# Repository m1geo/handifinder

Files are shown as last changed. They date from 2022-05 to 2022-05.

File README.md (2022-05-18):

# Handi-Finder
This repository is a KiCad 5.1 design of the published Handi-Finder DF project. 

The Handi-Finder Project is a radio direction finder, which connectso to an existing radio receiver such as a hand-held radio, and adds some direction finding capabiltiy to it.

The device works by switching between the two wire antennas mounted on H1 and H2 on the PCB. When the two antennas are directly lined towards the source of transmission, the arriving signal is in phase between both antennas. When the Handi-Finder is held non-squarely toward the signal source, the phase difference between the two wire antennas causes the switching frequency (here, approximately 1 kHz) to be audiable with loudness proportional to phase difference.

There are many resources online for this project, with some links here:
- [May 1993 QST Article by Bob K8DTS](https://www.ve5nn.ca/images/FoxHunt/handi-finder.pdf)
- [The HANDI-Finder](https://www.handi-finder.com/)

The [outputs](https://github.com/m1geo/handifinder/tree/main/Outputs) folder contains the Gerber files which can be zipped up and sent for manufacture at your chosen board-house.

## 3D View

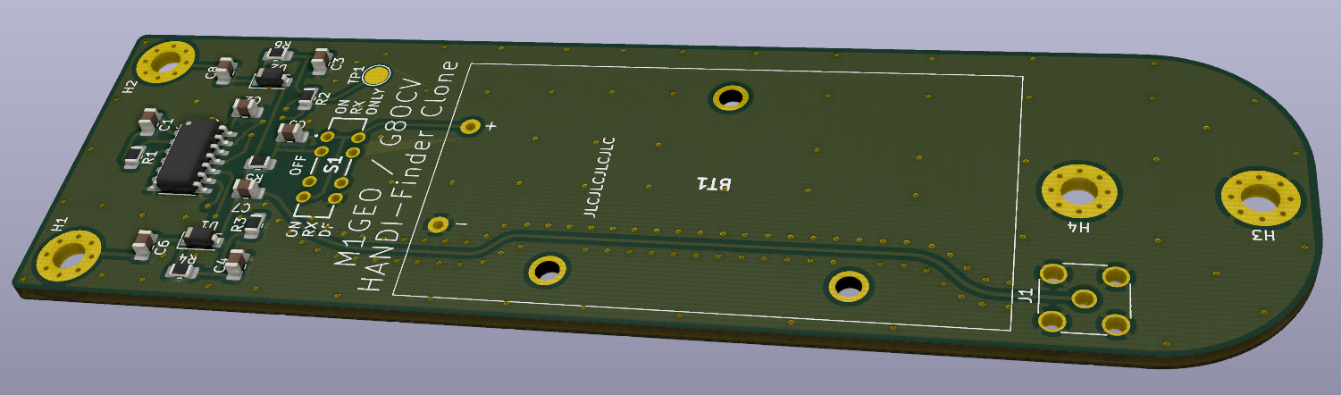
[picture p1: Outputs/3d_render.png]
3D View


## Schematic

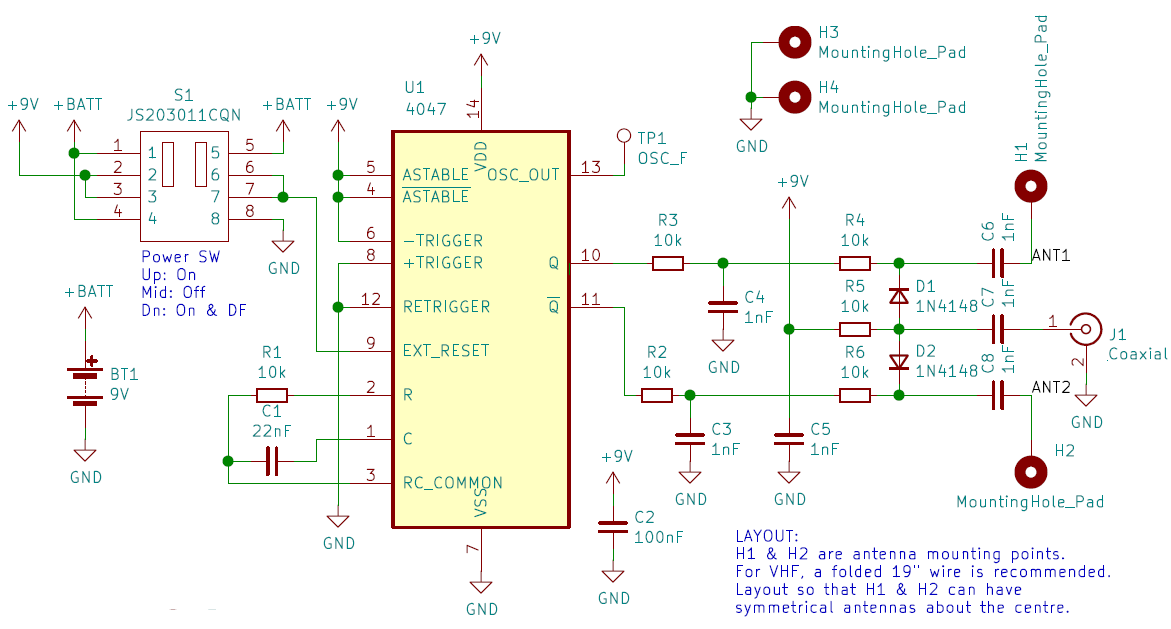
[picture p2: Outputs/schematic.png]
Schematic


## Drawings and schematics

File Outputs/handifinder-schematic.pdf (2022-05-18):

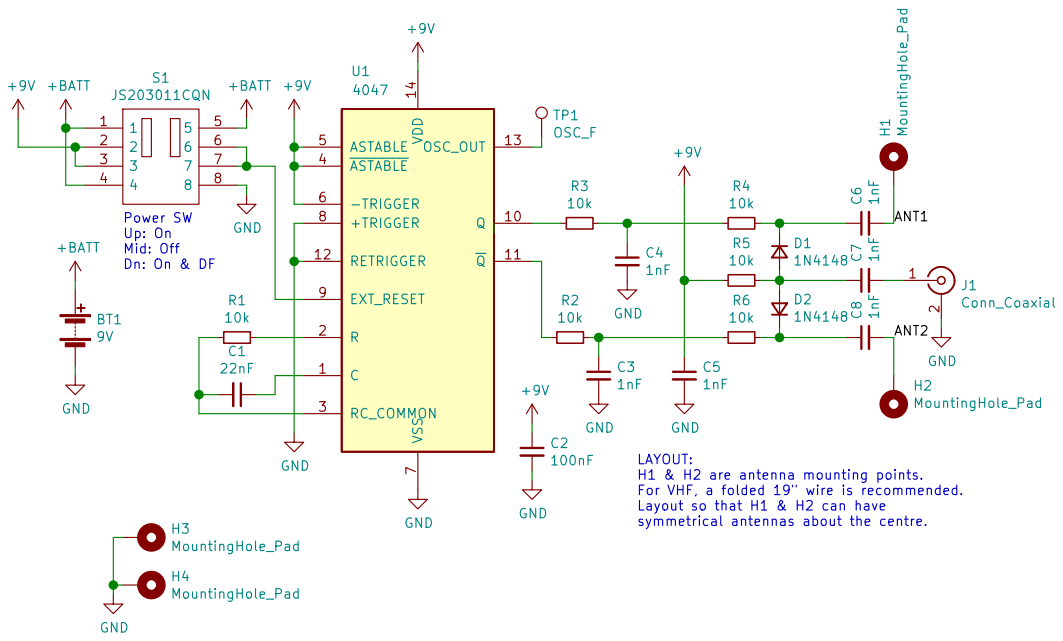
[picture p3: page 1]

ANT1 ANT2 Power SW
Up: On Mid: Off Dn: On & DF

https://github.com/m1geo/handifinder LAYOUT: H1 & H2 are antenna mounting points. For VHF, a folded 19" wire is recommended. Layout so that H1 & H2 can have

symmetrical antennas about the centre.

Id: 1/1 Title: HANDI-Finder File: handifinder.sch Sheet: / George Smart M1GEO

https://www.george-smart.co.uk/

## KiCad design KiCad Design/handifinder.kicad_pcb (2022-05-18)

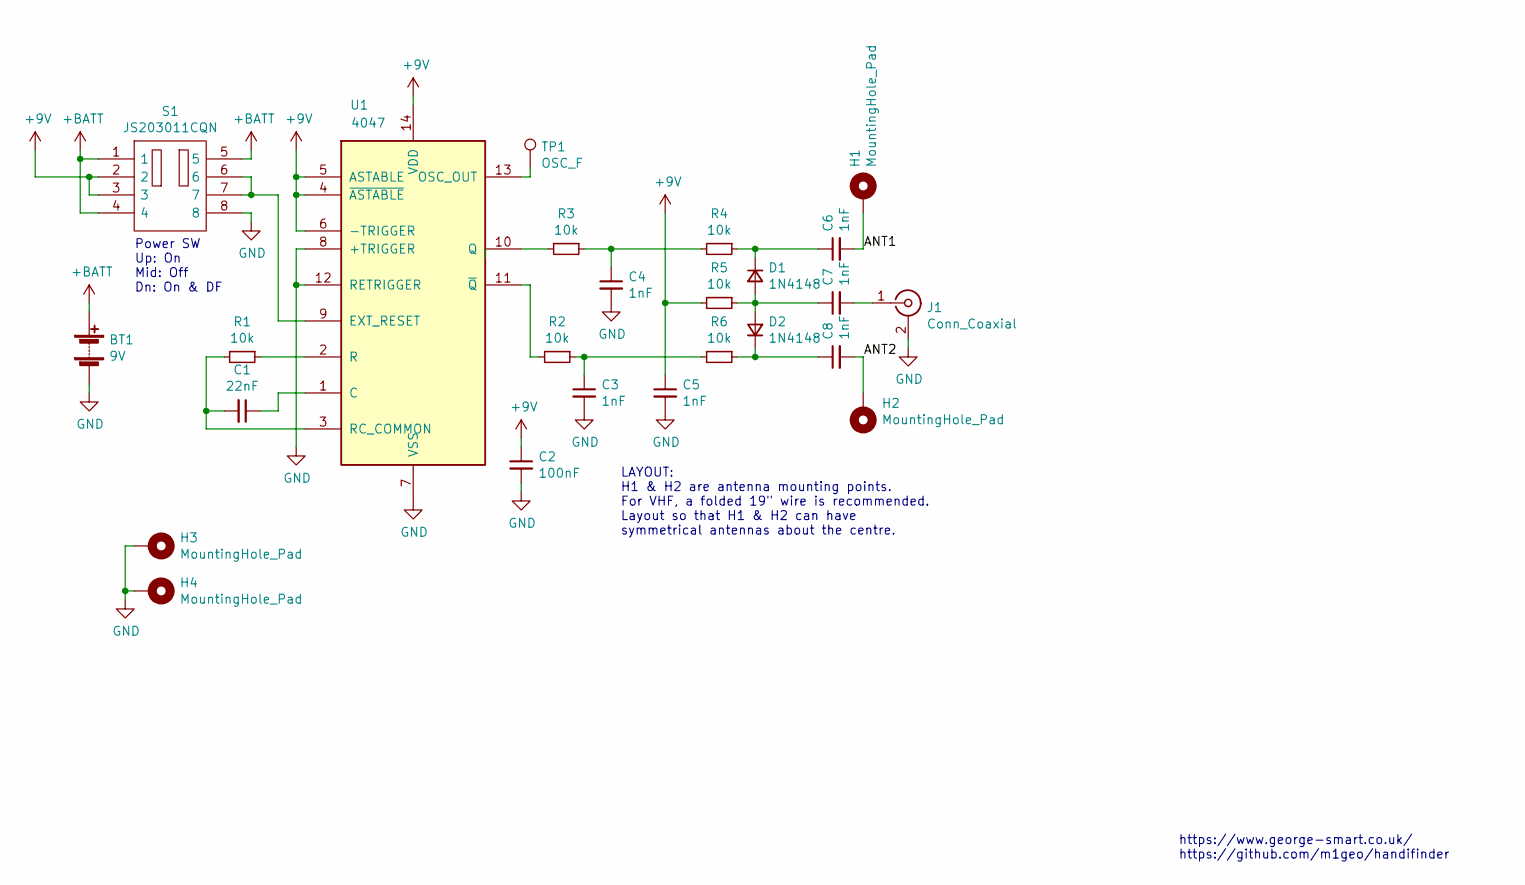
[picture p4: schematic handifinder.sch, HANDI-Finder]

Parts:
BT1: 9V; BH9VPC
C1: 22nF; C_0805_2012Metric_Pad1.18x1.45mm_HandSolder
C2: 100nF; C_0805_2012Metric_Pad1.18x1.45mm_HandSolder
C3, C4, C5, C6, C7, C8: 1nF; C_0805_2012Metric_Pad1.18x1.45mm_HandSolder
D1, D2: 1N4148; D_SOD-123
H1, H2, H3, H4: MountingHole_Pad; MountingHole_3.2mm_M3_Pad_Via
J1: Conn_Coaxial; SMA_Amphenol_132134_Vertical
R1, R2, R3, R4, R5, R6: 10k; R_0805_2012Metric_Pad1.20x1.40mm_HandSolder
S1: JS203011CQN; JS-DP3T; Manufacturer_Part_Number JS203011CQN; Mouser Part Number 611-JS203011CQN
TP1: OSC_F; TestPoint_Pad_D2.5mm
U1: 4047; SOIC-14_3.9x8.7mm_P1.27mm

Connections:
+9V: C2.1, C5.1, R5.2, S1.2, S1.3, U1.4 (~ASTABLE), U1.5 (ASTABLE), U1.6 (-TRIGGER), U1.14 (VDD)
+BATT: BT1.1 (+), S1.1, S1.4, S1.5
/ANT1: C6.2, H1.1
/ANT2: C8.2, H2.1
GND: BT1.2 (-), C2.2, C3.2, C4.2, C5.2, H3.1, H4.1, J1.2 (Ext), S1.8, U1.7 (VSS), U1.8 (+TRIGGER), U1.12 (RETRIGGER)
unnamed: C1.1, U1.1 (C)
unnamed: C1.2, R1.2, U1.3 (RC_COMMON)
unnamed: C3.1, R2.1, R6.2
unnamed: C4.1, R3.1, R4.2
unnamed: C6.1, D1.1 (K), R4.1
unnamed: C7.1, D1.2 (A), D2.2 (A), R5.1
unnamed: C7.2, J1.1 (In)
unnamed: C8.1, D2.1 (K), R6.1
unnamed: R1.1, U1.2 (R)
unnamed: R2.2, U1.11 (~Q)
unnamed: R3.2, U1.10 (Q)
unnamed: S1.6, S1.7, U1.9 (EXT_RESET)
unnamed: TP1.1, U1.13 (OSC_OUT)

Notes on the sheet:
https://www.george-smart.co.uk/ https://github.com/m1geo/handifinder
LAYOUT: H1 & H2 are antenna mounting points. For VHF, a folded 19" wire is recommended. Layout so that H1 & H2 can have symmetrical antennas about the centre.
Power SW Up: On Mid: Off Dn: On & DF

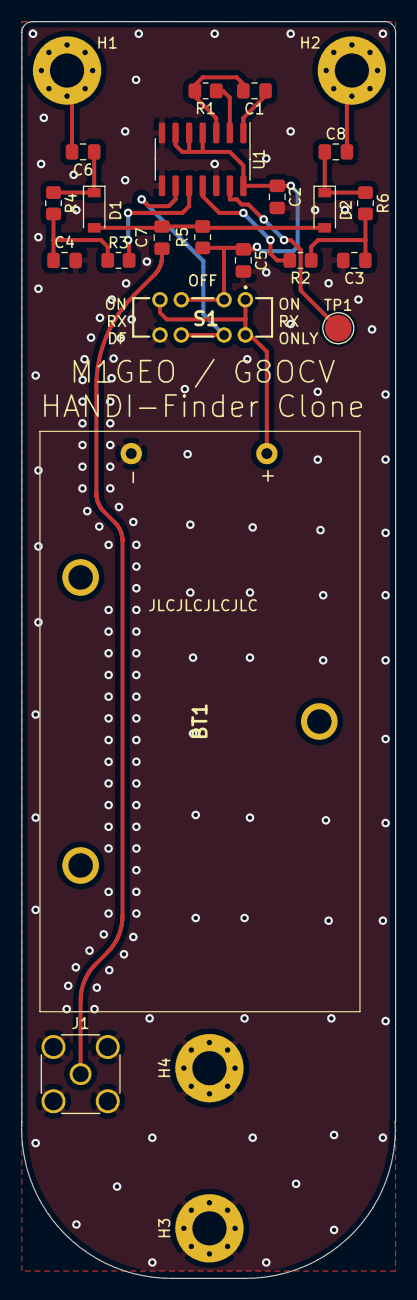
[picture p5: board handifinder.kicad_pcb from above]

Board: 2 copper layers, 35.0 x 117.7 mm, 25 parts (0 on the bottom side), 18 nets.
